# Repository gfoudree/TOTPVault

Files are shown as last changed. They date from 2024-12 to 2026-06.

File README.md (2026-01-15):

# TOTPVault

TOTPVault is a secure hardware vault for storing TOTP codes for two-factor authentication. It is compatible with websites and applications which support authenticators such as Google Authenticator or Authy.

TOTPVault uses an RISC-V ESP32-C3 microcontroller to perform cryptographic operations and storage/generation of TOTP codes with a separate chip to run an isolated USB stack.

<p align="center">
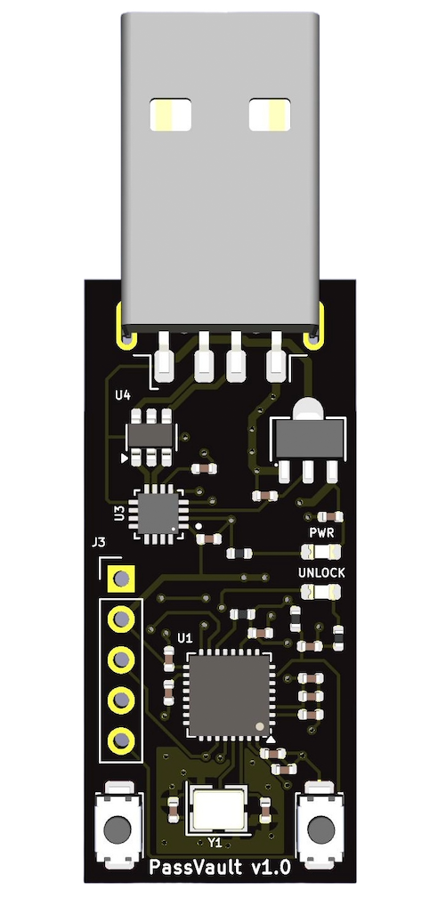
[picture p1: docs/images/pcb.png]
    
</p>

## Demo

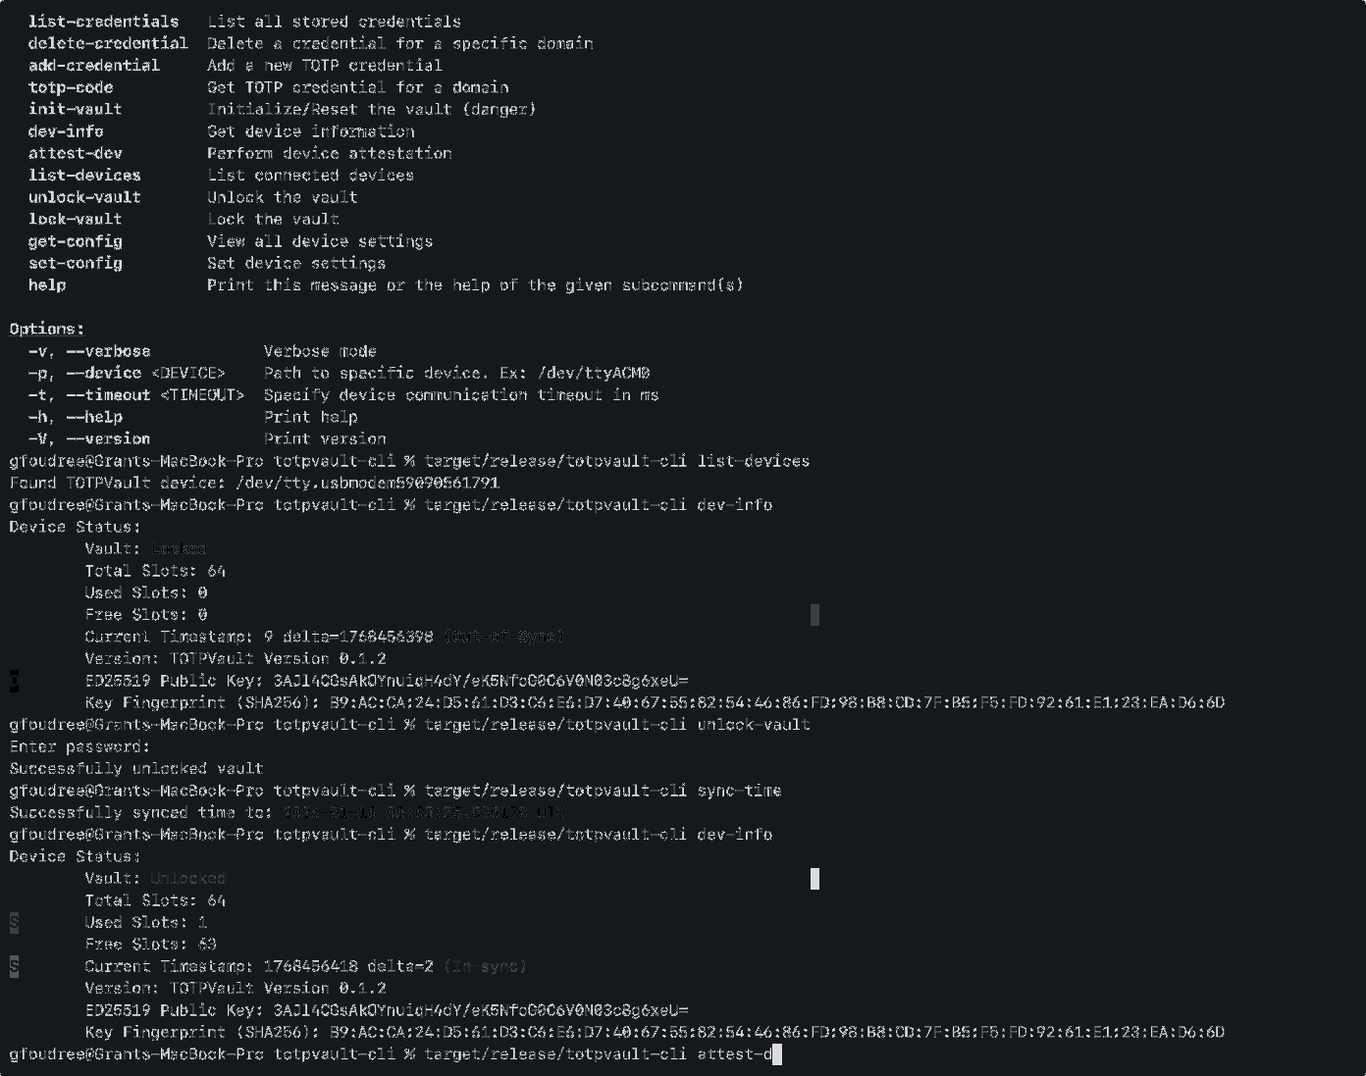
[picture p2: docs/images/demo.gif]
demo


## Features

- Support for up to 64 credentials
- Cross platform, no drivers needed for Linux/MacOS
- Open source firmware, software, and hardware!

### Security Features (summary)
- TOTP secrets stored with AES256, decryption key derived from vault password via PBKDF2
- Trusted firmware via secure boot with attestation available
- ESP32-C3 HW RNG used for cryptographic operations
- USB stack isolated to separate chip to minimize attack surface
- Hardware locked down (JTAG disabled, eFuses set, etc)

# System Architecture
[System Architecture](https://gfoudree.github.io/TOTPVault/system-design/)

## Installation

First, clone the repository and build the `totpvault-cli` tool and build it:

```bash
git clone https://github.com/gfoudree/totpvault
cd totpvault/totpvault-cli
cargo build -r
```

The CLI program will be located at: `target/release/totpvault-cli`
## Documentation

[Documentation](https://gfoudree.github.io/TOTPVault/)

# FAQ

#### Why choose ESP32-C3 for the microcontroller?
The ESP32 chips have strong hardware security features such as HWRNG, encryption/hashing support, secure boot, and encrypted flash.

Other chips have some or all of these features, however the ESP32-C3 is [PSA-L1 certified](https://products.psacertified.org/products/esp32-c3-series/certificates#security-level-1), has good support for Rust firmware, and is affordable.

#### The ESP32 has Wifi/Bluetooth, does this device use either?
No, there is no antenna on the board and the Wifi/Bluetooth stack is disabled in the firmware.

#### If somebody steals my device, can they generate TOTP codes for my accounts?
No, as long as your password is strong they cannot unlock the vault and generate codes.

## Authors

- [@gfoudree](https://www.github.com/gfoudree)

## License

[GNU GPLv3](https://choosealicense.com/licenses/gpl-3.0/)

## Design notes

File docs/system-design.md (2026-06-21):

# System Design

## Security Features

### Secret Storage
  - TOTP secrets are encrypted at rest using AES-256-GCM, ensuring data confidentiality
  - Encryption keys derived from vault password using Argon2id, device has no knowledge of decryption keys without vault password
  - The keys are never stored on the device (ie. the device cannot decrypt any secrets without the user providing the vault password)
  - Encrypted TOTP secrets are stored in NVS (flash) on the same die as the microcontroller, making it difficult to sniff/extract them
  - Secrets are zeroed from memory immediately after use
    <br/><br/>
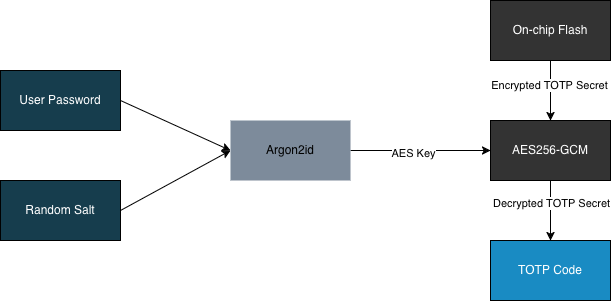
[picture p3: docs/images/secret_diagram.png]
System Diagram
    

### System Firmware
  - ESP32-C3 firmware has secure boot enabled with RSA 3072 signature verification, ensuring only trusted firmware can run
  - Firmware is encrypted using hardware-accelerated AES, providing an additional layer of security and mitigating TOCTOU attacks on secure boot
  - Firmware is written in Rust with minimal `unsafe` regions
  - Device can be attested with a challenge to prove itself
  - ESP32-C3 hardware random number generator is used for cryptographic operations
    <br/><br/>
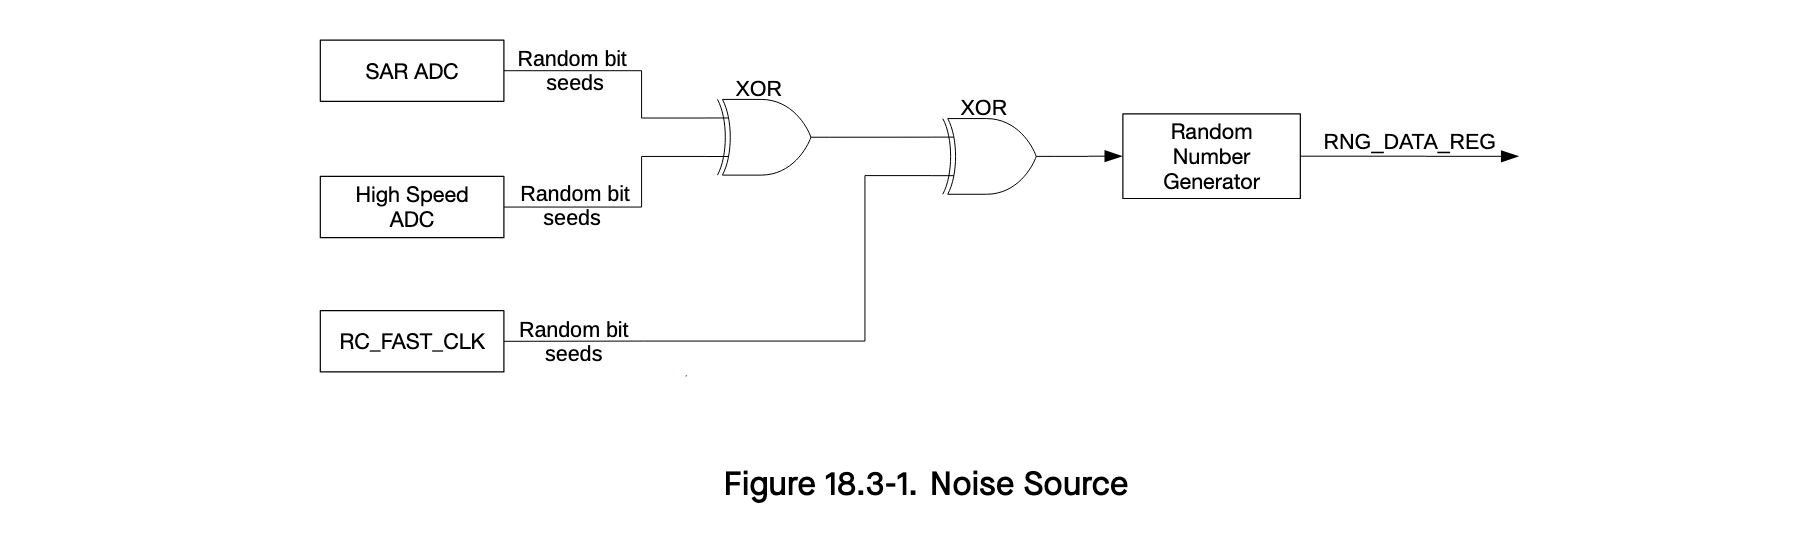
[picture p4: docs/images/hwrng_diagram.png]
HW RNG Design
    

### Hardware Design
  - TOTP secrets are encrypted and stored in on-chip flash memory, substantially complicating attacks to dump or snoop secrets
  - USB interface is delegated to a separate chip (CH343P) from the main microcontroller (ESP32-C3) in order to isolate any USB-level exploits from the main processor
    <br/><br/>
    USB Isolation

  - JTAG interfaces are disabled and eFuses locked down

## Security Limitations

- Communication between the `ESP32 <-> USB/UART Chip <-> Host` is *unencrypted*. After the vault has been unlocked, it is possible for an attacker to sniff these buses for plain-text TOTP codes and TOTP secrets (but only if the sniffing occurs while adding a new credential). It is impossible to extract a TOTP secret once it is stored.

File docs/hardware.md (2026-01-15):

# Hardware Overview

The TOTPVault device is designed with a focus on security and simplicity. Below is a detailed overview of its components and design.

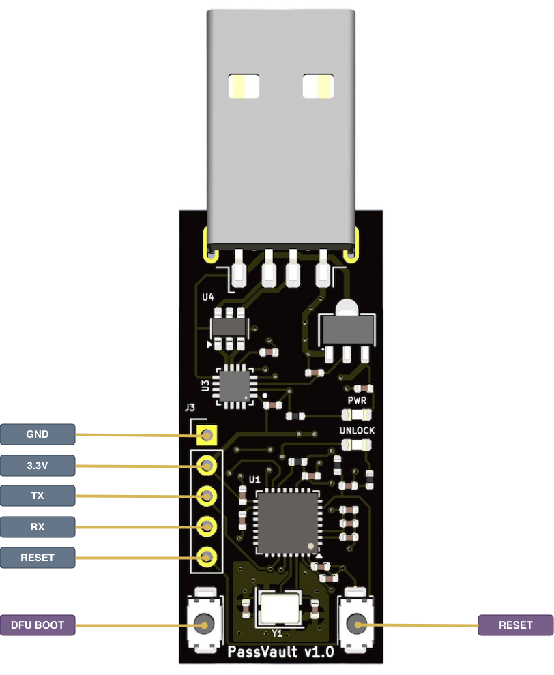
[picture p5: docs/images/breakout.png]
TOTPVault PCB Render


## Specifications

*   **Secure Processor**: ESP32-C3
    *   4MB Flash Storage
*   **USB-to-UART Adapter**: CH343P
*   **USB Connector**: USB-A
*   **Protection**: TVS Diode for static discharge protection on USB lines
*   **Debug Interface**: 5-pin header
    *   TX/RX (serial communication)
    *   3.3V Power
    *   Ground
    *   DFU mode pin
*   **Physical Buttons**:
    *   Reset button
    *   DFU mode button

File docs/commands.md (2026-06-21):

# TOTPVault CLI Commands

## Sync Time
Synchronize the system time with the device.

**Usage:**
```bash
totpvault-cli sync-time
```

**Example:**
```bash
totpvault-cli sync-time
Successfully synced time to: 1704892800
```

## List Credentials
List all stored credentials on the device.

**Usage:**
```bash
totpvault-cli list-credentials
```

**Example:**
```bash
totpvault-cli list-credentials
[Slot 0]: example.com
[Slot 1]: another-site.org
```

## Delete Credential
Delete a credential for a specific domain.

**Usage:**
```bash
totpvault-cli delete-credential --domain <domain_name>
```

**Example:**
```bash
totpvault-cli delete-credential --domain example.com
Successfully deleted credential
```

## Add Credential
Add a new TOTP credential.

**Usage:**
```bash
totpvault-cli add-credential --domain <domain_name>
```

**Example:**
```bash
totpvault-cli add-credential --domain new-service.net
Enter TOTP Secret Key: JBSWY3DPEHPK3PXP
Successfully added credential
```

## Totp Code
Get TOTP credential for a domain.

**Usage:**
```bash
totpvault-cli totp-code --domain <domain_name>
```

**Example:**
```bash
totpvault-cli totp-code --domain example.com
123456
25s remaining
```

## Init Vault
Initialize/Reset the vault (danger).

**Usage:**
```bash
totpvault-cli init-vault
```

**Example:**
```bash
totpvault-cli init-vault
**************** WARNING ****************
Initializing the vault will WIPE EXISTING CREDENTIALS!
Please make sure you will not be locked out of your accounts!

Do you want to continue? (yes/no): yes
Enter vault password:
Enter vault password (confirm):
Successfully initialized vault!
```

## Device Info
Get device information.

Free/Used slots is always `0` when the vault is locked for security reasons

**Usage:**
```bash
totpvault-cli dev-info
```

**Example:**
```bash
totpvault-cli dev-info
Device Status:
	Vault: Unlocked
	Total Slots: 10
	Used Slots: 2
	Free Slots: 8
	Current Timestamp: 1704892800 delta=0 (In-sync)
	Version: 1.0.0
	ED25519 Public Key: IiG0924qxqsDTs7TF8ZAexXJh2ZsRA5hcd9juC0tBGM=
	Key Fingerprint (SHA256): D9:42:BB:FB:7C:D8:B8:47:3D:AF:72:34:98:2B:44:61:4E:BD:8A:AD:32:97:52:C0:14:9C:96:63:5C:22:39:42
```

## Attest Device
Perform device attestation.

`<public_key>` should be the public key (not fingerprint) of the trusted device to send a challenge to.

**Usage:**
```bash
totpvault-cli attest-dev --key <public_key>
```

**Example:**
```bash
totpvault-cli attest-dev -k IiG0924qxqsDTs7TF8ZAexXJh2ZsRA5hcd9juC0tBGM=`
Public key: IiG0924qxqsDTs7TF8ZAexXJh2ZsRA5hcd9juC0tBGM=
Fingerprint (SHA256): D9:42:BB:FB:7C:D8:B8:47:3D:AF:72:34:98:2B:44:61:4E:BD:8A:AD:32:97:52:C0:14:9C:96:63:5C:22:39:42
Successfully attested device
```

## List Devices
List connected devices.

Use `-v` to view detailed information

**Usage:**
```bash
totpvault-cli list-devices
```

**Example:**
```bash
totpvault-cli list-devices
Found TOTPVault device: /dev/ttyACM0
```

## Unlock Vault
Unlock the vault

**Usage:**
```bash
totpvault-cli unlock-vault
```

**Example:**
```bash
totpvault-cli unlock-vault
Enter password:
Successfully unlocked vault
```

## Lock Vault
Lock the vault

**Usage:**
```bash
totpvault-cli lock-vault
```

**Example:**
```bash
totpvault-cli lock-vault
Locked vault
```

## Get Settings
Gets all settings and their values for the device

**Usage:**
```bash
totpvault-cli get-config
```

**Example:**
```bash
totpvault-cli get-config
Device Settings:
        auto-lock: off
```

## Set Autolock
Sets the autolock feature for the vault (locks vault after 10 min)

**Usage:**
```bash
totpvault-cli set-config --vault-autolock <on/off>
```

**Example:**
```bash
totpvault-cli set-config --vault-autolock off
Successfully set setting 'autolock' to 'off'

totpvault-cli set-config --vault-autolock on
Successfully set setting 'autolock' to 'on'
```

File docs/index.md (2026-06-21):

# Introduction

# TOTPVault

TOTPVault is a secure hardware vault for storing TOTP codes for two-factor authentication. It is compatible with websites and applications which support authenticators such as Google Authenticator or Authy.

For a detailed look at the hardware components, see the [Hardware Overview](hardware.md).

Device
# Websites Tested
TOTPVault should work on almost all TOTP-based authentication sites, the list below shows which ones have been validated to be working

| Website | Supported |
|---|---|
| Google | Y |
| Digital Ocean | Y |
| Amazon | Y |
| Microsoft | Y |
| Instagram | Y |
| Paypal | Y |
| eBay | Y |
| Cloudflare | Y |
| Dropbox | Y |
| Github | Y |
| Gitlab | Y |
| Linkedin | Y |
| Protonmail | Y |

# FAQ
### Why choose ESP32-C3 for the microcontroller?
The ESP32 chips have strong hardware security features such as HWRNG, encryption/hashing support, secure boot, and encrypted flash.

Other chips have some or all of these features, however the ESP32-C3 is [PSA-L1 certified](https://products.psacertified.org/products/esp32-c3-series/certificates#security-level-1), has good support for Rust firmware, and is affordable.

### The ESP32 has Wifi/Bluetooth, does this device use either?
No, there is no antenna on the board and the Wifi/Bluetooth stack is disabled in the firmware.

### If somebody steals my device, can they generate TOTP codes for my accounts?
No, as long as your password is strong they cannot unlock the vault and generate codes.

# Troubleshooting
### Device does not show up
Try reinserting the device and look for a USB device with the VID 0x1A86 and PID 0x55D3. 

You can run `dev-info -v` which will print verbose output as to how the device is selected. It is possible another device exists with the same VID/PID in which case use `-p` to specify the path to the exact device

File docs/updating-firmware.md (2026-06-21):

# Updating Firmware

## Requirements
- Linux or Windows system
  - MacOS is not supported due to a driver issue with the USB <-> UART chip CH343p
  - There is a MacOS driver, but it is untested and the status is unknown: [https://github.com/WCHSoftGroup/ch34xser_macos](https://github.com/WCHSoftGroup/ch34xser_macos_)
- Espressif [`esptool`](https://docs.espressif.com/projects/esptool/en/latest/esp32c3/installation.html)

## Steps
- Install `esptool`: `pip install esptool`

- Download the latest firmware version `flash.bin`

- Push and hold the DFU button on the device (left button) while inserting it into the computer, then release the DFU button

- Identify the device `esptool security-info`

```bash
esptool v5.3.0
Connected to ESP32-C3 on /dev/cu.usbserial-TFGTNDFV:
Chip type:          ESP32-C3 in Secure Download Mode

Security Information:
=====================
Flags: 0x000004f5 (0b10011110101)
Key Purposes: (0, 0, 9, 8, 4, 0, 12)
  BLOCK_KEY0 - USER/EMPTY
  BLOCK_KEY1 - USER/EMPTY
  BLOCK_KEY2 - SECURE_BOOT_DIGEST0
  BLOCK_KEY3 - HMAC_UP
  BLOCK_KEY4 - XTS_AES_128_KEY
  BLOCK_KEY5 - USER/EMPTY
Chip ID: 5
API Version: 3
Secure Boot: Enabled
Secure Boot Key Revocation Status:
        Secure Boot Key1 is Revoked
        Secure Boot Key2 is Revoked

Flash Encryption: Enabled
SPI Boot Crypt Count (SPI_BOOT_CRYPT_CNT): 0x1
Icache in UART download mode: Disabled
JTAG: Permanently Disabled
```

- Flash the new firmware with `esptool --chip esp32c3 -p <SERIAL PORT> --no-stub write-flash --no-compress --force --flash-mode dio --flash-freq 80m --flash-size 4MB 0x0 flash.bin`

```bash
esptool v5.3.0
Connected to ESP32-C3 on /dev/cu.usbserial-TFGTNDFV:
Chip type:          ESP32-C3 in Secure Download Mode

Enabling default SPI flash mode...
Configuring flash size...
Warning: Security features enabled, so not changing any flash settings.
Flash will be erased from 0x00000000 to 0x003fffff...
Wrote 4194304 bytes at 0x00000000 in 421.7 seconds (79.6 kbit/s).
Cannot verify written data if encrypted or in secure download mode.

Hard resetting via RTS pin...
```

- Unplug and reinsert the device

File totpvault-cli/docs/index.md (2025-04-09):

# Introduction

Welcome to the TOTPVault documentation. This guide will help you understand how to use and manage your TOTPVault device.

# Websites Tested
TOTPVault should work on almost all TOTP-based authentication sites. The list below just shows which ones have been validated to be working

| Website | Supported |
|---|---|
| Google | Y |
| Digital Ocean | |
| Amazon | |
| Microsoft | |
| Instagram | |
| Paypal | |
| eBay | |
| Cloudflare | |
| Dropbox | |
| Github | |
| Gitlab | |
| Linkedin | |
| Protonmail | |

# FAQ
### Why choose ESP32 for the microcontroller?
The ESP32 has Wifi/Bluetooth, does this device use either? No, there is no antenna on the board and the Wifi/Bluetooth stack is disabled in the firmware

### If somebody steals my device, can they generate TOTP codes for my accounts? 
No, as long as your password is strong they cannot unlock the vault and generate codes

# Troubleshooting
### Device does not show up
Try reinserting the device and looking for a USB device with the VID 0x1A86 and PID 0x55D3. 

You can run `dev-info -v` which will print verbose output as to how the device is selected. It is possible another device exists with the same VID/PID in which case use `-p` to specify the path to the exact device

### "unexpected end of file" Error

```
Unable to get device status from: /dev/tty.usbmodem59090561791
	Error = IO error while reading data: unexpected end of file
```
 The device is taking a while to perform operations, increase the timeout in the user application to wait for it

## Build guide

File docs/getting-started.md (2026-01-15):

# Getting Started

## Installation

First, clone the repository and build the `totpvault-cli` tool:

```bash
git clone https://github.com/gfoudree/totpvault
cd totpvault/totpvault-cli
cargo build -r
```
The executable will be located at `target/release/totpvault-cli`. You can optionally move it to a directory in your `PATH` for easier access.

## Find the TOTPVault device
Insert the device into your computer and search for it
```bash
$ totpvault-cli dev-info

Device Status:
	Vault: Locked
	Total Slots: 64
	Used Slots: 0
	Free Slots: 0
	Current Timestamp: 89 (Out-of-Sync)
	Version: TOTPVault Version 0.1
	Public Key: 2ppFZmElF9eAIi2QaJtwG9y2g3oJAPU/izSje4AbTFQ=
	Key Fingerprint: 4C:FD:D5:D2:9B:70:59:8A:...
```

If you don't see the device, try running with `-v` to see the verbose output. You can manually specify a device with `-p`

## Initialize the vault
Initialize the vault with a strong password. This wipes all existing credentials in the vault, beware!
```bash
$ totpvault-cli init-vault

**************** WARNING ****************
Initializing the vault will WIPE EXISTING CREDENTIALS!
Please make sure you will not be locked out of your accounts!

Do you want to continue? (yes/no):
yes
Enter vault password:
Enter vault password (confirm):
Successfully initialized vault!
```

## Unlock the vault
```bash
$ totpvault-cli unlock-vault

Enter password:
Successfully unlocked vault
```

## Sync time
Time must be synced to the vault on power reset as there is no battery-powered clock. **Inaccurate time will result in invalid TOTP codes**

```bash
$ totpvault-cli sync-time

Successfully synced time to: 2026-01-10 05:44:50.866425 UTC
```

## Verify time-sync and unlocked status
```bash
$ totpvault-cli dev-info

Device Status:
	Vault: Unlocked
	Total Slots: 64
	Used Slots: 0
	Free Slots: 64
	Current Timestamp: 1768023870 delta=2 (In-sync)
	Version: TOTPVault Version 0.1
	ED25519 Public Key: IiG0924qxqsDTs7TF8ZAexXJh2ZsRA5hcd9juC0tBGM=
	Key Fingerprint (SHA256): D9:42:BB:FB:7C:D8:B8:47:3D:AF:72:34:98:2B:44:61:4E:BD:8A:AD:32:97:52:C0:14:9C:96:63:5C:22:39:42
```
`Vault: Unlocked` and `Current Timestamp: 1768023870 (In-sync)` shows that the vault's time is in sync

Note the key fingerprint `D9:42:BB:FB:7C:D8...`. This is the fingerprint of the public key of the device which can be used to authenticate it.

## Add a credential
Login to the account you wish to add and enable a new TOTP credential

When the QR code displays, there should be a option such as "can't scan code" which displays a string such as `r7uk mfjw zboh 3x3u ccij bptu leeq thk6`

Next, run the following command pasting the string from above
```bash
$ totpvault-cli add-credential --domain-name google.com

Enter TOTP Secret Key:
Successfully added credential
```

It is wise to keep a backup 2FA device/method available in case you lose your TOTPVault token!

## List credentials
```bash
$ totpvault-cli list-credentials

[Slot 0]: google.com
```

## Get TOTP code
If the code is incorrect, wait until the next code rolls over (or 30+ sec) since there can be a small delay with the device generating the code
```bash
$ totpvault-cli totp-code -d google.com

056086
11s remaining
```

Refer to the [Commands](commands.md) section for detailed usage of each command.

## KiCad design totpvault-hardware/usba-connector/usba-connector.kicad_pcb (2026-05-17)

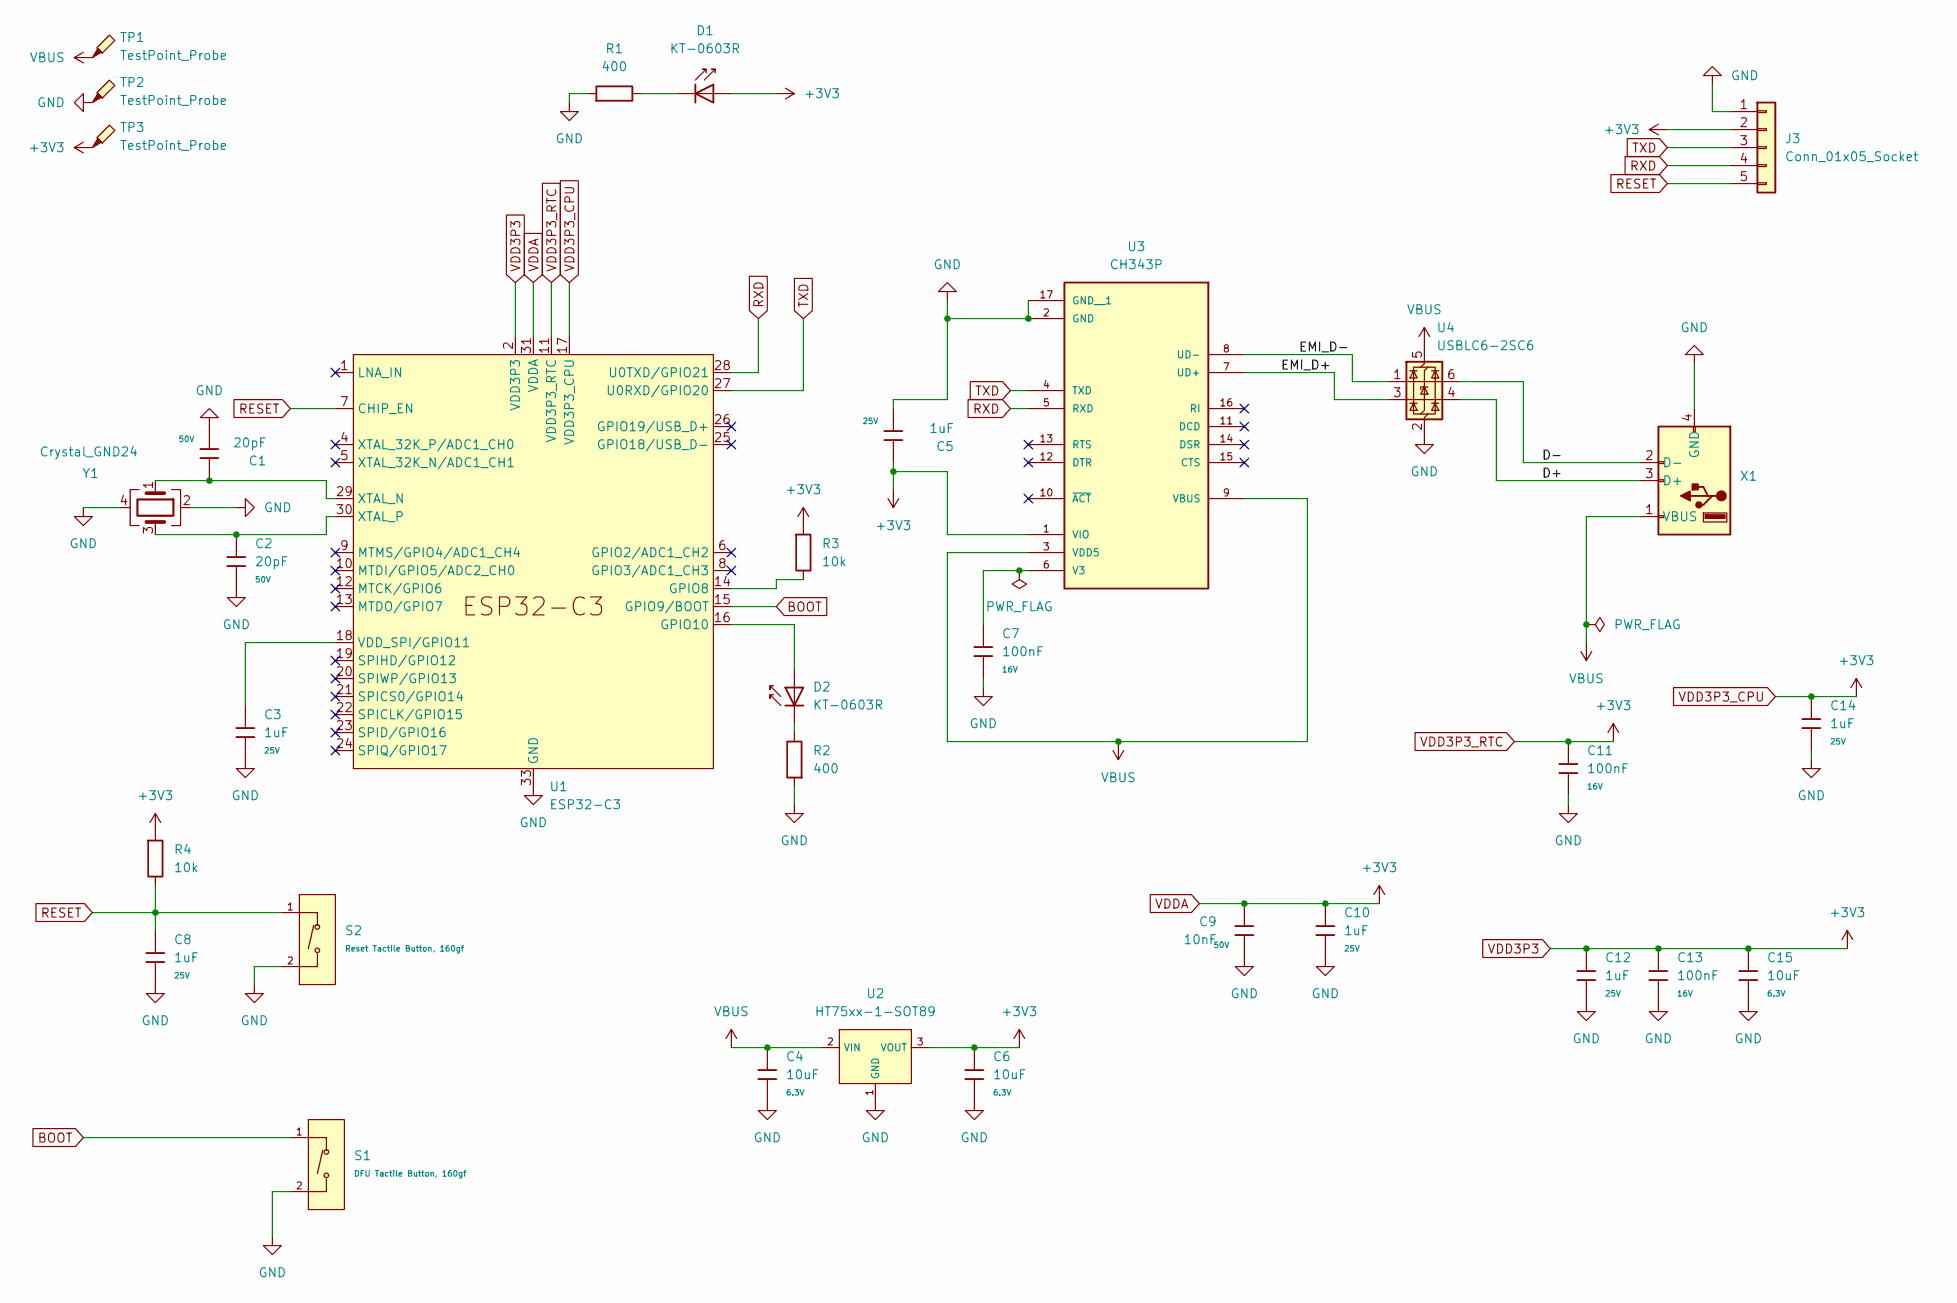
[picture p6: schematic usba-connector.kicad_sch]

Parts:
C1, C2: 20pF; C_0402; Voltage Rated 50V; Tolerance ±5%; Part 0402CG200J500NT; LCSC C1554
C3, C5, C8, C10, C12, C14: 1uF; C_0402; Voltage Rated 25V; Tolerance ±10%; Part CL05A105KA5NQNC; LCSC C52923
C4, C6, C15: 10uF; C_0402; Voltage Rated 6.3V; Tolerance ±20%; Part CL05A106MQ5NUNC; LCSC C15525
C7, C11, C13: 100nF; C_0402; Voltage Rated 16V; Tolerance ±10%; Part CL05B104KO5NNNC; LCSC C1525
C9: 10nF; C_0402; Voltage Rated 50V; Tolerance ±10%; Part CL05B103KB5NNNC; LCSC C15195
D1, D2: KT-0603R; D_0603; Part KT-0603R; LCSC C2286
J3: Conn_01x05_Socket; PinHeader_1x05_P2.54mm_Vertical
R1, R2: 400; R_0402; Overload Voltage (Max) 50V; Tolerance ±1%; Part 0402WGF1200TCE; LCSC C25079
R3, R4: 10k; R_0402; Overload Voltage (Max) 50V; Tolerance ±1%; Part 0402WGF1002TCE; LCSC C25744
S1: DFU Tactile Button, 160gf; SW_TS-1088-AR02016; Voltage Rating (Dc) 12V; Part TS-1088-AR02016; LCSC C720477
S2: Reset Tactile Button, 160gf; SW_TS-1088-AR02016; Voltage Rating (Dc) 12V; Part TS-1088-AR02016; LCSC C720477
TP1, TP2, TP3: TestPoint_Probe; TestPoint_Pad_D1.0mm
U1: ESP32-C3; QFN-32-1EP_5x5mm_P0.5mm_EP3.45x3.45mm
U2: HT75xx-1-SOT89; SOT-89-3_L4.5-W2.5-P1.50-LS4.2-BR; Output Voltage 3.3V; Dropout Voltage 55mV@(1mA); Part HT7533-1; LCSC C14289
U3: CH343P; PARTREV 1E
U4: USBLC6-2SC6; SOT-23-6
X1: USB_A_Molex_48037-2200_Horizontal
Y1: Crystal_GND24; Crystal_SMD_3225-4Pin_3.2x2.5mm

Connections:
/D+: U4.4 (I/O2), X1.3 (D+)
/D-: U4.6 (I/O1), X1.2 (D-)
/EMI_D+: U3.7 (UD+), U4.3 (I/O2)
/EMI_D-: U3.8 (UD-), U4.1 (I/O1)
BOOT: S1.1 (A), U1.15 (GPIO9/BOOT)
GND: C1.2, C2.2, C3.2, C4.2, C5.2, C6.2, C7.2, C8.2, C9.2, C10.2, C11.2, C12.2, C13.2, C14.2, C15.2, J3.1, R1.1, R2.1, S1.2 (B), S2.2 (B), TP2.1, U1.33 (GND), U2.1 (GND), U3.2 (GND), U3.17 (GND__1), U4.2 (GND), X1.4 (GND), Y1.2, Y1.4
unnamed: D1.1, R1.2
unnamed: D2.1, R2.2
unnamed: R3.2, U1.14 (GPIO8)
unnamed: D2.2, U1.16 (GPIO10)
unnamed: C3.1, U1.18 (VDD_SPI/GPIO11)
unnamed: C1.1, U1.29 (XTAL_N), Y1.1
unnamed: C2.1, U1.30 (XTAL_P), Y1.3
unnamed: C7.1, U3.6 (V3)
RESET: C8.1, J3.5, R4.2, S2.1 (A), U1.7 (CHIP_EN)
RXD: J3.4, U1.28 (U0TXD/GPIO21), U3.5 (RXD)
TXD: J3.3, U1.27 (U0RXD/GPIO20), U3.4 (TXD)
VBUS: C4.1, TP1.1, U2.2 (VIN), U3.3 (VDD5), U3.9 (VBUS), U4.5 (VBUS), X1.1 (VBUS)
VDD3P3: C5.1, C6.1, C9.1, C10.1, C11.1, C12.1, C13.1, C14.1, C15.1, D1.2, J3.2, R3.1, R4.1, TP3.1, U1.2 (VDD3P3), U1.3 (VDD3P3), U1.11 (VDD3P3_RTC), U1.17 (VDD3P3_CPU), U1.31 (VDDA), U1.32 (VDDA), U2.3 (VOUT), U3.1 (VIO)

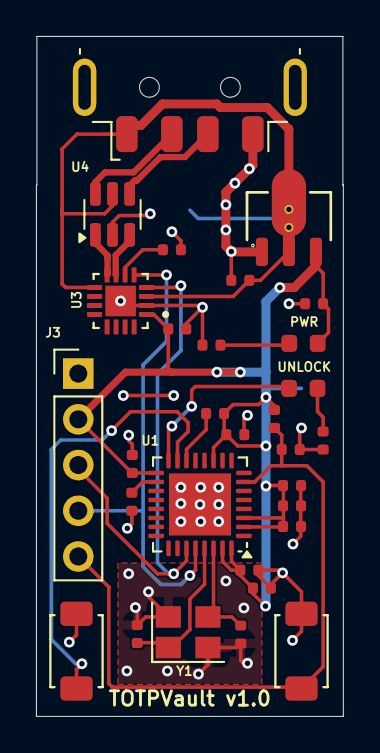
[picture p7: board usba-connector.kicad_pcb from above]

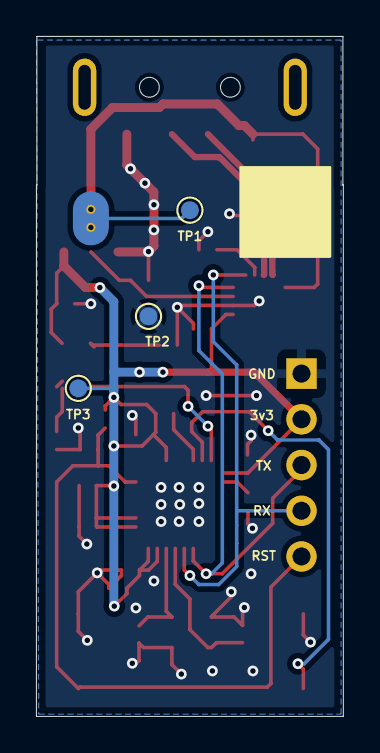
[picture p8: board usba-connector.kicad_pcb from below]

Board: 2 copper layers, 17.1 x 37.8 mm, 33 parts (3 on the bottom side), 19 nets.

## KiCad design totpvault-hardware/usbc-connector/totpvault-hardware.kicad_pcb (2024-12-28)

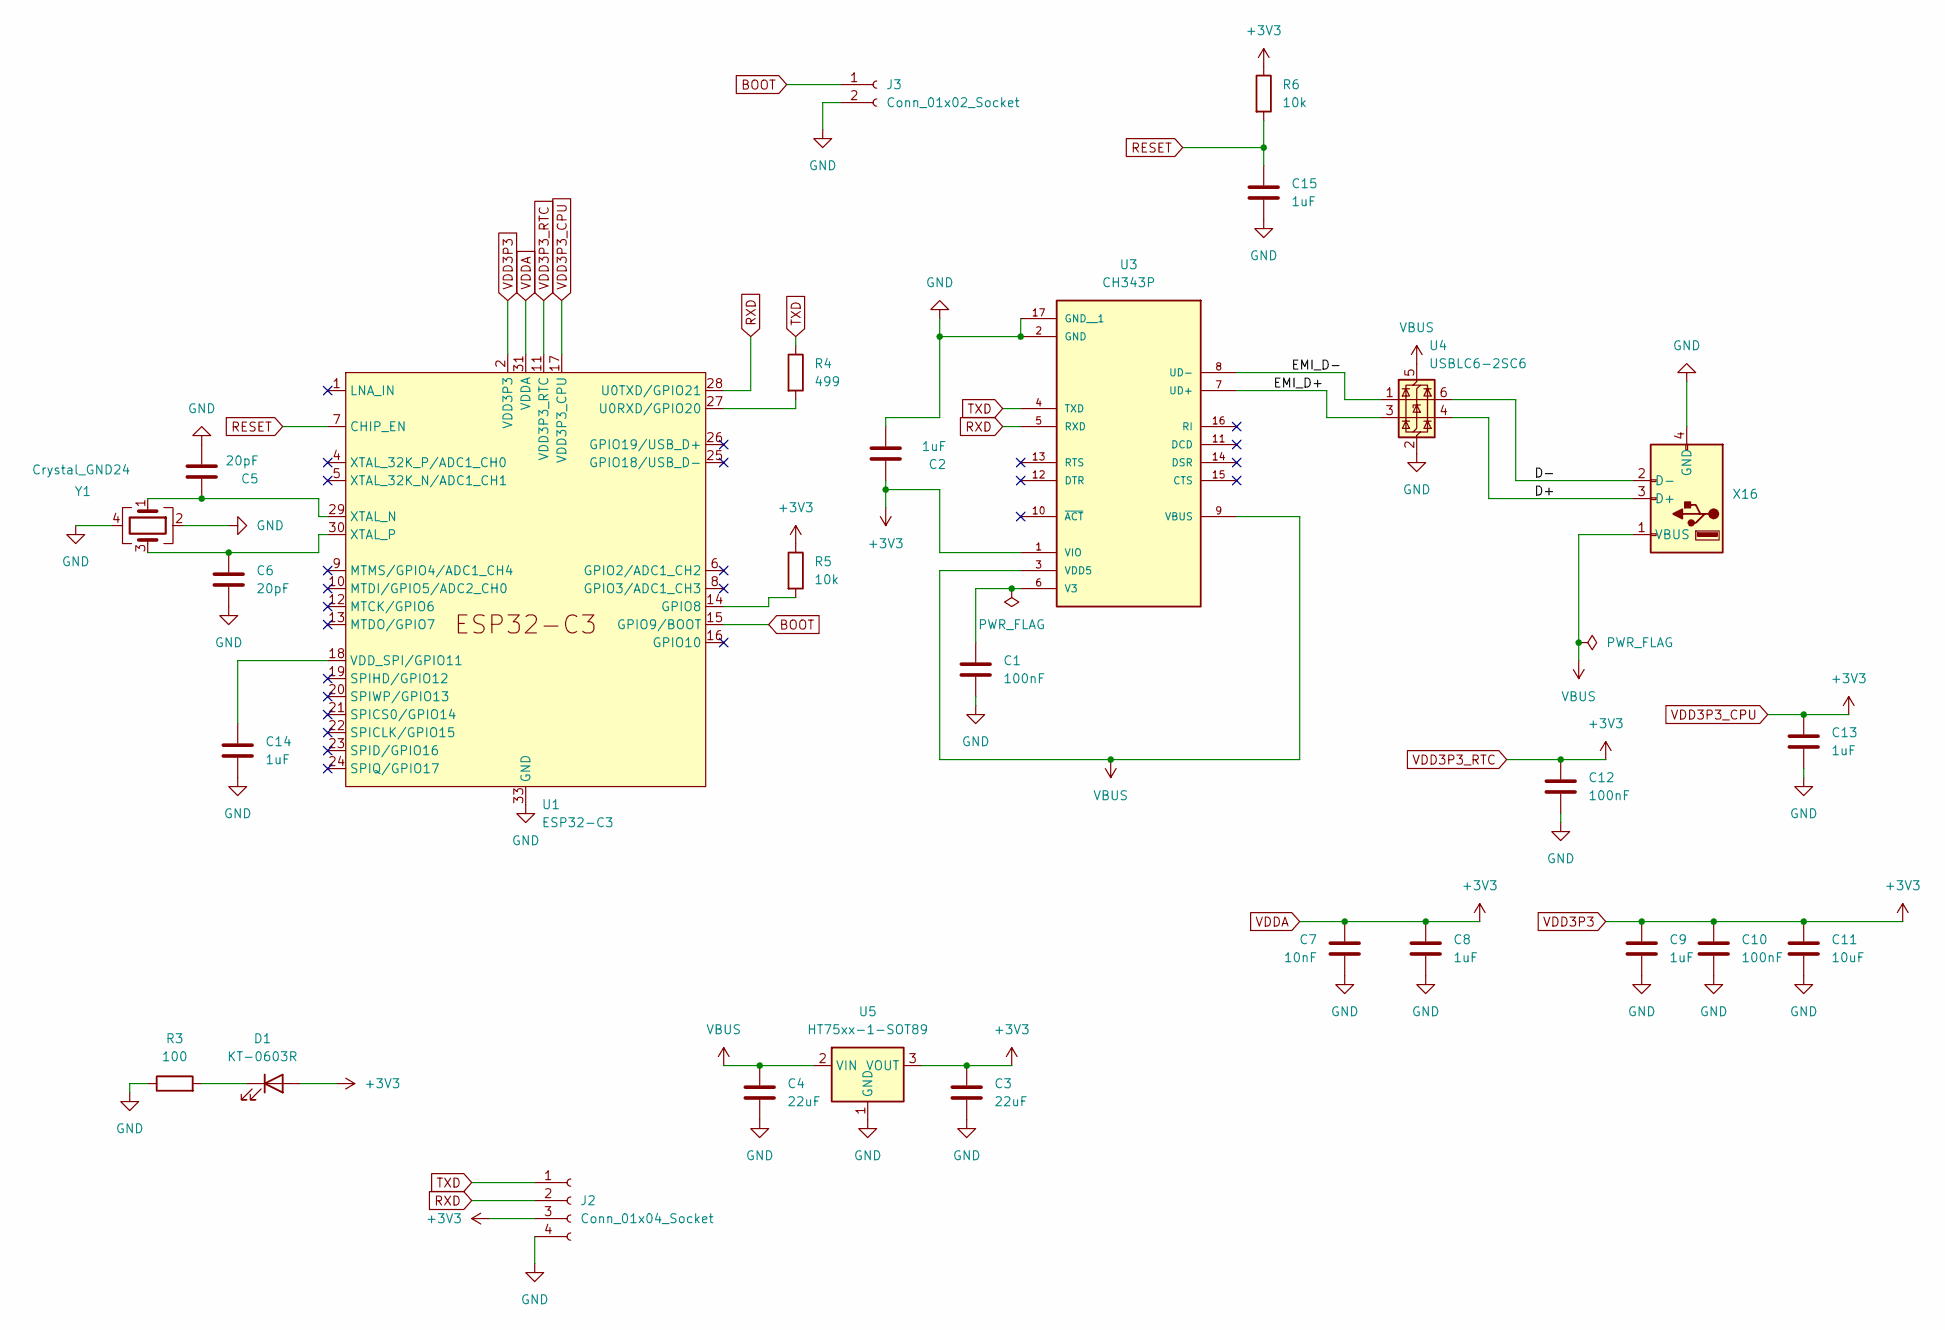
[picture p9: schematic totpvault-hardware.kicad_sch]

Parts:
C1, C10, C12: 100nF; C_0603_1608Metric
C2, C8, C9, C13, C14, C15: 1uF; C_0603_1608Metric
C3, C4: 22uF; C_0603_1608Metric
C5, C6: 20pF; C_0402_1005Metric
C7: 10nF; C_0603_1608Metric
C11: 10uF; C_0603_1608Metric
D1: KT-0603R; LED_0603_1608Metric
J2: Conn_01x04_Socket; PinHeader_1x04_P2.54mm_Vertical
J3: Conn_01x02_Socket; PinHeader_1x02_P2.54mm_Vertical
R3: 100; R_0603_1608Metric
R4: 499; R_0603_1608Metric
R5, R6: 10k; R_0603_1608Metric
U1: ESP32-C3; QFN-32-1EP_5x5mm_P0.5mm_EP3.45x3.45mm
U3: CH343P; PARTREV 1E
U4: USBLC6-2SC6; SOT-23-6
U5: HT75xx-1-SOT89; SOT-89-3
X16: USB_C_Connector
Y1: Crystal_GND24; Crystal_SMD_3225-4Pin_3.2x2.5mm

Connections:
/D+: U4.4 (I/O2), X16.3 (D+)
/D-: U4.6 (I/O1), X16.2 (D-)
/EMI_D+: U3.7 (UD+), U4.3 (I/O2)
/EMI_D-: U3.8 (UD-), U4.1 (I/O1)
BOOT: J3.1, U1.15 (GPIO9/BOOT)
GND: C1.2, C2.2, C3.2, C4.2, C5.2, C6.2, C7.2, C8.2, C9.2, C10.2, C11.2, C12.2, C13.2, C14.2, C15.2, J2.4, J3.2, R3.1, U1.33 (GND), U3.2 (GND), U3.17 (GND__1), U4.2 (GND), U5.1 (GND), X16.4 (GND), Y1.2, Y1.4
unnamed: D1.1 (K), R3.2
unnamed: R5.2, U1.14 (GPIO8)
unnamed: R4.2, U1.27 (U0RXD/GPIO20)
unnamed: C14.1, U1.18 (VDD_SPI/GPIO11)
unnamed: C5.1, U1.29 (XTAL_N), Y1.1
unnamed: C6.1, U1.30 (XTAL_P), Y1.3
unnamed: C1.1, U3.6 (V3)
RESET: C15.1, R6.2, U1.7 (CHIP_EN)
RXD: J2.2, U1.28 (U0TXD/GPIO21), U3.5 (RXD)
TXD: J2.1, R4.1, U3.4 (TXD)
VBUS: C4.1, U3.3 (VDD5), U3.9 (VBUS), U4.5 (VBUS), U5.2 (VIN), X16.1 (VBUS)
VDD3P3: C2.1, C3.1, C7.1, C8.1, C9.1, C10.1, C11.1, C12.1, C13.1, D1.2 (A), J2.3, R5.1, R6.1, U1.2 (VDD3P3), U1.3 (VDD3P3), U1.11 (VDD3P3_RTC), U1.17 (VDD3P3_CPU), U1.31 (VDDA), U1.32 (VDDA), U3.1 (VIO), U5.3 (VOUT)

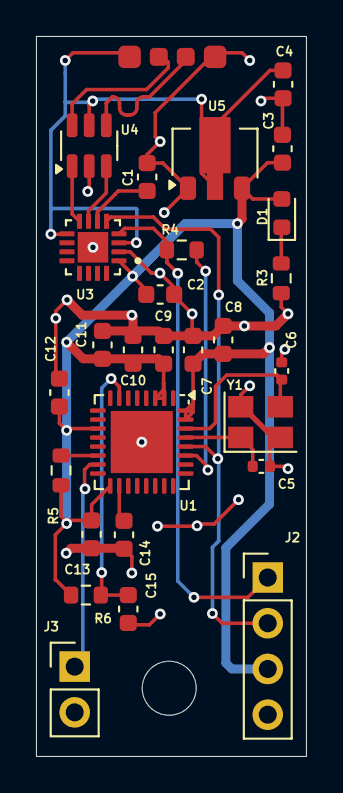
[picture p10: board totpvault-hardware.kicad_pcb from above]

Board: 2 copper layers, 15.0 x 40.0 mm, 28 parts (0 on the bottom side), 18 nets.

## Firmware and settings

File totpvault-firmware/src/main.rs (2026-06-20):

use argon2::{Algorithm, Argon2, Params, Version};
use base64::Engine;
use base64::prelude::BASE64_STANDARD;
use chrono::Utc;
use core::cell::Cell;
use credential::{Credential, MAX_CREDENTIALS};
use critical_section::Mutex;
use crypto::{gen_ed25519_keypair, gen_salt, get_ed25519_public_key_nvs, sign_challenge};
use ed25519_dalek::SECRET_KEY_LENGTH;
use esp_idf_svc::hal::gpio::{Gpio10, InterruptType, Output, PinDriver, Pull};
use esp_idf_svc::hal::timer::{TimerConfig, TimerDriver};
use esp_idf_svc::nvs::{EspDefaultNvsPartition, EspNvsPartition, NvsDefault};
use esp_idf_svc::{
    hal::{gpio::AnyIOPin, prelude::Peripherals, reset::restart, uart, units::Hertz},
    sys,
};
use esp_idf_sys::{ESP_OK, esp_efuse_mac_get_default};
use log::{error, info};
use rmp_serde::Serializer;
use serde::Serialize;
use std::collections::HashMap;
use std::fmt::Debug;
use subtle::ConstantTimeEq;
use totpvault_lib;
use totpvault_lib::*;
use zeroize::{Zeroize, ZeroizeOnDrop};

use crate::crypto::AES_KEY_LEN;

mod credential;
mod crypto;
mod storage;

// Static (global) variable for 'static lifetime. Mutex for safety, Cell<bool> allows multiple mutable references by only allowing 'interior mutability'
static VAULT_STATUS_UNLOCKED: Mutex<Cell<bool>> = Mutex::new(Cell::new(false));

#[derive(Zeroize, ZeroizeOnDrop)] // Have key zeroize on all dropped paths
struct System {
    time_set: bool,
    key: [u8; 32],

    // Authentication rate limiters
    auth_window_ts: i64,
    auth_counter: u32,
    auth_block_until: i64,

    #[zeroize(skip)]
    settings: HashMap<String, String>,
    #[zeroize(skip)]
    nvs_storage: storage::Storage,
    #[zeroize(skip)]
    nvs_partition_handle: EspNvsPartition<NvsDefault>,
}

impl System {
    fn new(nvs_partition: EspNvsPartition<NvsDefault>) -> System {
        System {
            time_set: false,
            key: [0; 32],
            auth_window_ts: 0,
            auth_counter: 0,
            auth_block_until: 0,
            settings: HashMap::new(),
            nvs_storage: storage::Storage::new(nvs_partition.clone()).unwrap(),
            nvs_partition_handle: nvs_partition,
        }
    }

    fn load_settings(&mut self) {
        // Iterate through all of the known settings by their NVS keys
        for key in ALL_SETTINGS {
            match self.nvs_storage.nvs_read_setting(key) {
                Ok(value) => {
                    self.settings.insert(key.to_string(), value);
                }
                Err(_) => {
                    // If setting not found in the NVS, initialize with default and save
                    let default_value = match key {
                        SETTING_AUTOLOCK => AUTOLOCK_OFF,
                        _ => {
                            error!("Unknown setting key during load: {}", key);
                            continue; // Skip unknown settings
                        }
                    };
                    if let Err(write_err) = self.nvs_storage.nvs_write_setting(key, default_value) {
                        error!(
                            "Failed to write default setting {} = {}: {}",
                            key, default_value, write_err
                        );
                    } else {
                        self.settings
                            .insert(key.to_string(), default_value.to_string());
                    }
                }
            }
        }
    }

    /// Updates a K-V setting in the NVS and live system state. Returns the previous value of the setting
    fn set_setting(&mut self, set_msg: &SetSettingMsg) -> Result<String, String> {
        if !set_msg.validate() {
            return Err("Invalid setting key or value".to_string());
        }

        // Get current value of the setting
        let cur_val = self.settings.get(&set_msg.key).unwrap().clone();

        // Update in NVS
        self.nvs_storage
            .nvs_write_setting(&set_msg.key, &set_msg.value)?;

        // Update in current system state
        self.settings
            .insert(set_msg.key.to_string(), set_msg.value.clone());

        Ok(cur_val.to_string())
    }

    fn get_all_settings(&self) -> GetSettingsResponseMsg {
        GetSettingsResponseMsg {
            settings: self.settings.clone(),
        }
    }

    fn setup_ed25519(&mut self) -> Result<(), String> {
        let mut secret_bytes: [u8; SECRET_KEY_LENGTH] = gen_ed25519_keypair().to_bytes();
        self.nvs_storage
            .nvs_write_blob(NVS_KEY_ED25519, &secret_bytes)?;
        secret_bytes.zeroize();
        Ok(())
    }

    fn init_vault(&mut self, cmd_buf: &[u8; 512], read_bytes: usize) -> Result<(), String> {
        let init_msg = rmp_serde::from_slice::<InitVaultMsg>(&cmd_buf[1..read_bytes])
            .map_err(|e| format!("Invalid InitVault message: {}", e))?;

        if !init_msg.validate() {
            return Err("Invalid InitVault message".to_string());
        }

        // Lock the vault and zeroize the key before re-initializing.
        // This handles the case where init_vault is called while the vault is already unlocked.
        critical_section::with(|cs| VAULT_STATUS_UNLOCKED.borrow(cs).set(false));
        self.key.zeroize();

        // Erase NVS partition
        self.nvs_storage
            .format_nvs_partition(self.nvs_partition_handle.clone())?;
        self.setup_ed25519()?;

        // Generate encryption salt and store it in the database
        let salt = gen_salt();
        self.nvs_storage.nvs_write_blob("salt", &salt)?;

        // Derive the encryption key
        let enc_key = Self::derive_encryption_key(init_msg.password.as_str(), &salt)?;

        // Wipe all entries
        for i in 0..MAX_CREDENTIALS {
            Credential::init_credential(i, &mut self.nvs_storage)?;
        }

        // Init metadata
        self.nvs_storage
            .nvs_write_blob_encrypted("magic", &ENCRYPTION_MAGIC, &enc_key)?;

        Ok(())
    }

    fn attest(&mut self, challenge_msg_bytes: &[u8]) -> Result<AttestationResponseMsg, String> {
        let challenge_msg =
            rmp_serde::from_slice::<AuthenticateChallengeMsg>(&challenge_msg_bytes[1..])
                .map_err(|_| "Invalid AuthenticateChallenge message")?;
        if !challenge_msg.validate() {
            return Err("Invalid AuthenticateChallenge message".to_string());
        }

        let challenge_bytes_vec = BASE64_STANDARD
            .decode(challenge_msg.nonce_challenge.clone())
            .map_err(|_| "Invalid AuthenticateChallenge message")?;

        let challenge_bytes: [u8; NONCE_CHALLENGE_LEN] = challenge_bytes_vec
            .try_into()
            .map_err(|_| "Invalid AuthenticateChallenge message")?;

        match sign_challenge(&challenge_bytes, &mut self.nvs_storage) {
            Ok(sig) => {
                let signature_encoded = BASE64_STANDARD.encode(sig.to_vec());
                Ok(AttestationResponseMsg {
                    message: signature_encoded,
                })
            }
            Err(e) => Err(format!("Error signing challenge! {}", e)),
        }
    }

    pub fn derive_encryption_key(
        password: &str,
        salt: &[u8; SALT_LEN],
    ) -> Result<[u8; AES_KEY_LEN], String> {
        let params = Params::new(ARGON2_M_COST, ARGON2_T_COST, ARGON2_P_COST, Some(32))
            .map_err(|e| format!("Invalid Argon2 parameters: {e}"))?;
        let argon2 = Argon2::new(Algorithm::Argon2id, Version::V0x13, params);

        let mut key = [0u8; AES_KEY_LEN];
        argon2
            .hash_password_into(password.as_bytes(), salt, &mut key)
            .map_err(|e| format!("Argon2id key derivation failed: {e}"))?;
        Ok(key)
    }

    fn display_code(&mut self, cmd_buf: &[u8; 512], read_bytes: usize) -> Result<String, String> {
        if self.time_set == false {
            return Err("System time has not been set!".to_string());
        }

        match rmp_serde::from_slice::<DisplayCodeMsg>(&cmd_buf[1..read_bytes]) {
            Ok(display_code_msg) => {
                let index = Credential::credential_name_to_index(
                    display_code_msg.domain_name.to_lowercase(),
                    &self.key,
                    &mut self.nvs_storage,
                )?;
                let mut cred = Credential::get_credential(index, &self.key, &mut self.nvs_storage)?;

                let totp_code = Credential::gen_totp(&cred)?;
                cred.totp_secret_decrypted.zeroize();
                Ok(totp_code)
            }
            Err(_e) => Err("Invalid display code message".to_string()),
        }
    }

    pub fn unlock_vault(
        &mut self,
        cmd_buf: &[u8; 512],
        read_bytes: usize,
        unlocked_led: &mut PinDriver<Gpio10, Output>,
    ) -> Result<(), String> {
        let unlock_msg = rmp_serde::from_slice::<UnlockMsg>(&cmd_buf[1..read_bytes])
            .map_err(|_| "Invalid Unlock message".to_string())?;

        if !unlock_msg.validate() {
            return Err("Invalid Unlock message".to_string());
        }

        // System time can only go forward within a defined delta when vault is unlocked
        let cur_ts = Utc::now().timestamp();

        // Check cooldown timer
        if cur_ts < self.auth_block_until {
            return Err(format!(
                "Too many login attempts, please wait {} seconds",
                LOGIN_COOLDOWN_SECS
            ));
        }

        // Reset rolling authentication window
        if cur_ts - self.auth_window_ts > LOGIN_COOLDOWN_WINDOW_SECS as i64 {
            self.auth_window_ts = cur_ts;
            self.auth_counter = 0;
        }

        // Check the rate limit
        self.auth_counter = self.auth_counter.saturating_add(1);
        if self.auth_counter > MAX_FAILED_AUTH_ATTEMPTS {
            self.auth_block_until = cur_ts + LOGIN_COOLDOWN_SECS as i64;

            return Err(format!(
                "Too many login attempts, please wait {} seconds",
                LOGIN_COOLDOWN_SECS
            ));
        }

        // Read the salt, toss error if it fails ("?"), then try and convert into slice with SALT_LEN and handle error if it fails
        let salt: [u8; SALT_LEN] = match self.nvs_storage.nvs_read_blob("salt")?.try_into() {
            Ok(v) => v,
            Err(_) => {
                return Err(
                    "Database is corrupted, salt is not a valid length. Please reset the database!"
                        .to_string(),
                );
            }
        };

        let key = Self::derive_encryption_key(unlock_msg.password.as_str(), &salt)?;

        // Test if the vault is unlocked
        let decrypted_magic = self
            .nvs_storage
            .nvs_read_blob_encrypted("magic", &key)
            .map_err(|_| {
                "Unable to decrypt value. Corrupted data or wrong password!".to_string()
            })?;

        // Use constant time compare for security, although it's not necessary maybe since GCM mode authenticates decrypted block
        if decrypted_magic.ct_ne(&ENCRYPTION_MAGIC).unwrap_u8() == 1 {
            return Err("Invalid password".to_string());
        }

        self.key = key;
        critical_section::with(|cs| VAULT_STATUS_UNLOCKED.borrow(cs).set(true));

        // Set board LED GPIO10 to on for unlocked
        unlocked_led.set_high().unwrap();

        // Reset auth counter
        self.auth_window_ts = 0;
        self.auth_counter = 0;
        self.auth_block_until = 0;

        Ok(())
    }

    /// Sets the system time counter
    ///
    /// # Overview
    ///
    /// Parses an incoming set time message with a timestamp. Sets system time ONLY if it is greater than the current time AND it's
    /// within an allowed delta `MAX_TIMESTAMP_SET_DELTA` of the current timestamp
    ///
    fn set_time(&mut self, cmd_buf: &[u8; 512], read_bytes: usize) -> Result<(), String> {
        let time_msg = rmp_serde::from_slice::<SetTimeMsg>(&cmd_buf[1..read_bytes])
            .map_err(|_| "Invalid SetTime message".to_string())?;

        if !time_msg.validate() {
            return Err("Invalid SetTime message".to_string());
        }

        let new_unix_timestamp = time_msg.unix_timestamp;

        if self.time_set {
            // Time has been set already, check if the new time is more than the max allowed delta
            let mut current_tv = sys::timeval {
                tv_sec: 0,
                tv_usec: 0,
            };
            let res: i32;
            unsafe {
                res = sys::gettimeofday(&mut current_tv, core::ptr::null_mut());
            }
            if res != 0 {
                return Err("Unable to set time of day!".to_string());
            }

            // Is the new timestamp LESS than the current one OR is the difference between the new and old one > the allowed delta?
            if new_unix_timestamp < current_tv.tv_sec as u64
                || (new_unix_timestamp - current_tv.tv_sec as u64) > MAX_TIMESTAMP_SET_DELTA
            {
                return Err("Invalid timestamp".to_string());
            }
        }
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
fn main() {
    // It is necessary to call this function once, otherwise some patches to the runtime
    // implemented by esp-idf-sys might not link properly. See https://github.com/esp-rs/esp-idf-template/issues/71
    esp_idf_svc::sys::link_patches();
    esp_idf_svc::log::EspLogger::initialize_default();

    #[cfg(debug_assertions)]
    unsafe {
        std::env::set_var("RUST_BACKTRACE", "1");
    }

    // Enable HW RNG. We are not using RF, so we need to use the ADC to feed the RNG. https://docs.espressif.com/projects/esp-idf/en/stable/esp32/api-reference/system/random.html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
    unsafe {
        sys::bootloader_random_enable();
    }
    info!("Hardware RNG enabled");

    let nvs_partition: EspNvsPartition<NvsDefault> = EspDefaultNvsPartition::take().unwrap();
    let mut sys = System::new(nvs_partition.clone());
    sys.load_settings(); // Load settings on system initialization

    let peripherals = Peripherals::take().unwrap();

    let config = uart::config::Config::default()
        .baudrate(Hertz(115_200))
        .flow_control(uart::config::FlowControl::None);

    // Setup status LED and lock button
    let mut unlocked_led = PinDriver::output(peripherals.pins.gpio10).unwrap();
    unlocked_led.set_low().unwrap();
    let mut lock_button = PinDriver::input(peripherals.pins.gpio9).unwrap();
    lock_button.set_pull(Pull::Up).unwrap(); // Pull "BOOT" button up
    lock_button
        .set_interrupt_type(InterruptType::PosEdge)
        .unwrap();

    // Lock button handler
    unsafe {
        lock_button.subscribe(timer_callback_lock_vault).unwrap();
    }

    lock_button.enable_interrupt().unwrap();

    let timer_config = TimerConfig::new().auto_reload(false); // Auto-reload = false for one-shot timer
    let mut autolock_timer = TimerDriver::new(peripherals.timer00, &timer_config).unwrap();
    unsafe {
        autolock_timer.subscribe(timer_callback_lock_vault).unwrap();
    }

    if let Err(e) = sys.first_boot_hook() {
        error!("Critical error on first boot! {e}");
        sys.key.zeroize();
        restart();
    }

    // After this line, logging stops working as UART is taken over for host <-> dev communication
    let mut uart: uart::UartDriver = uart::UartDriver::new(
        peripherals.uart1,
        peripherals.pins.gpio21,
        peripherals.pins.gpio20,
        Option::<AnyIOPin>::None,
        Option::<AnyIOPin>::None,
        &config,
    )
    .expect("Error initializing UART Driver");

    loop {
        std::thread::sleep(std::time::Duration::from_millis(100));

        // Update vault locked LED
        match get_vault_unlock_status() {
            true => unlocked_led.set_high().unwrap(),
            false => {
                unlocked_led.set_low().unwrap();
                sys.key.zeroize(); // Also zeroize out the key. Handles situation when vault is locked via interrupt
            }
        }

        let mut buf: [u8; 512] = [0; 512];
        if let Ok(num_bytes_read) = uart.read(&mut buf, 10) {
            if num_bytes_read > 0 {
                let command = buf[0];

                // Only the CMD_LOCK_VAULT, CMD_DEV_INFO, CMD_LIST, CMD_GET_SETTINGS commands are one byte, the rest should be 2+ bytes
                let min_required_len = match command {
                    CMD_LOCK_VAULT | CMD_DEV_INFO | CMD_LIST | CMD_GET_SETTINGS => 1,
                    _ => 2,
                };
                if num_bytes_read < min_required_len {
                    send_response_message(&mut uart, "Invalid command length", true);
                    continue;
                }

                match command {
                    CMD_SET_TIME => {
                        if get_vault_unlock_status() == false {
                            send_response_message(&mut uart, "Vault Locked!", true)
                        } else {
                            match sys.set_time(&buf, num_bytes_read) {
                                Ok(_) => send_response_message(&mut uart, SUCCESS_MSG, false),
                                Err(e) => send_response_message(&mut uart, e.as_str(), true),
                            }
                        }
                    }
                    CMD_CREATE => {
                        if get_vault_unlock_status() == false {
                            send_response_message(&mut uart, "Vault Locked!", true)
                        } else {
                            match sys.create_entry(&buf, num_bytes_read) {
                                Ok(_) => send_response_message(&mut uart, SUCCESS_MSG, false),
                                Err(e) => send_response_message(&mut uart, e.as_str(), true),
                            }
                        }
                    }
                    CMD_LIST => {
                        if get_vault_unlock_status() == false {
                            send_response_message(&mut uart, "Vault Locked!", true)
                        } else {
                            match Credential::list_credentials(&sys.key, &mut sys.nvs_storage) {
                                Ok(creds) => {
                                    // Transform them into CredentialListMsg
                                    let creds_vec = creds
                                        .iter()
                                        .map(|cred| CredentialInfo {
                                            domain_name: cred.domain_name.clone(),
                                            slot_id: cred.slot_id,
                                        })
                                        .collect();
                                    let cred_list_msg = CredentialListMsg {
                                        credentials: creds_vec,
                                    };
                                    send_message(&mut uart, &cred_list_msg);
                                }
                                Err(e) => send_response_message(&mut uart, e.as_str(), true),
                            }
                        }
                    }
                    CMD_DELETE => {
                        if get_vault_unlock_status() == false {
                            send_response_message(&mut uart, "Vault Locked!", true)
                        } else {
                            if let Ok(del_msg) =
                                rmp_serde::from_slice::<DeleteEntryMsg>(&buf[1..num_bytes_read])
                            {
                                if del_msg.validate() {
                                    match Credential::delete_credential_by_name(
                                        del_msg.domain_name.to_lowercase(),
                                        &sys.key,
                                        &mut sys.nvs_storage,
                                    ) {
                                        Ok(_) => {
                                            send_response_message(&mut uart, SUCCESS_MSG, false)
                                        }
                                        Err(e) => send_response_message(
                                            &mut uart,
                                            format!("Error deleting credential: {}", e).as_str(),
                                            true,
                                        ),
                                    }
                                } else {
                                    send_response_message(
                                        &mut uart,
                                        "Invalid DeleteMsg message",
                                        true,
                                    );
                                }
                            } else {
                                send_response_message(&mut uart, "Invalid DeleteMsg message", true);
                            }
                        }
                    }
                    CMD_DISPLAY_CODE => {
                        if get_vault_unlock_status() == false {
                            send_response_message(&mut uart, "Vault Locked!", true)
                        } else {
                            match sys.display_code(&buf, num_bytes_read) {
                                Ok(totp_code) => {
                                    let totp_code_msg = TOTPCodeMsg {
                                        totp_code: totp_code,
                                        system_timestamp: Utc::now().timestamp() as u64,
                                    };
                                    send_message(&mut uart, &totp_code_msg);
                                }
                                Err(e) => send_response_message(
                                    &mut uart,
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

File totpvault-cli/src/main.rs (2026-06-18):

use crate::dev::TotpvaultDev;
use chrono::Utc;
use clap::{Args, Parser, Subcommand};
use colored::Colorize;
use env_logger::Builder;
use log::{debug, warn};
use totpvault_lib::{MIN_PW_LEN, SystemInfoMsg};
use zeroize::Zeroize;

mod comm;
mod dev;
mod tests;

#[derive(Parser)]
#[command(name = "totpvault-cli")]
#[command(about = "CLI tool to manage TOTPVault", version = "1.0.0")]
struct Cli {
    #[arg(short, long, global = true, required = false, help = "Verbose mode")]
    verbose: bool,
    #[arg(
        short = 'p',
        long,
        global = true,
        required = false,
        help = "Path to specific device. Ex: /dev/ttyACM0"
    )]
    device: Option<String>,
    #[arg(
        short = 't',
        long,
        global = true,
        required = false,
        help = "Specify device communication timeout in ms"
    )]
    timeout: Option<u64>,
    #[command(subcommand)]
    command: Commands,
}

#[derive(Subcommand)]
enum Commands {
    #[command(about = "Synchronize the system time")]
    SyncTime,

    #[command(about = "List all stored credentials")]
    ListCredentials,

    #[command(about = "Delete a credential for a specific domain")]
    DeleteCredential(DomainArgs),

    #[command(about = "Add a new TOTP credential")]
    AddCredential(DomainArgs),

    #[command(about = "Get TOTP credential for a domain")]
    TotpCode(DomainArgs),

    #[command(about = "Initialize/Reset the vault (danger)")]
    InitVault,

    #[command(about = "Get device information")]
    DevInfo,

    #[command(about = "Perform device attestation")]
    AttestDev(PublicKeyArgs),

    #[command(about = "List connected devices")]
    ListDevices,

    #[command(about = "Unlock the vault")]
    UnlockVault,

    #[command(about = "Lock the vault")]
    LockVault,

    #[command(about = "View all device settings")]
    GetConfig,

    #[command(about = "Set device settings")]
    SetConfig(SetConfigArgs),
}

#[derive(Args)]
struct DomainArgs {
    #[arg(
        short = 'd',
        long,
        required = true,
        help = "Domain name of the TOTP code to get"
    )]
    domain_name: String,
}

#[derive(Args)]
struct PublicKeyArgs {
    #[arg(
        short = 'k',
        long,
        required = false,
        help = "Public key of the device to attest"
    )]
    public_key: Option<String>,
}

#[derive(Args)]
struct SetConfigArgs {
    #[arg(long, value_parser = ["on", "off"], help = "Set the vault to automatically lock after 10min ('on' or 'off')")]
    vault_autolock: Option<String>,
}

fn get_device(cli: &Cli) -> Result<String, ()> {
    if let Some(device) = cli.device.clone() {
        Ok(device)
    } else {
        if let Ok(device) = TotpvaultDev::find_device() {
            Ok(device)
        } else {
            Err(())
        }
    }
}

fn dump_device_status(device_status: &SystemInfoMsg) {
    let locked_msg = match device_status.vault_unlocked {
        true => "Unlocked".green(),
        false => "Locked".bold().red(),
    };

    let timestamp_msg = match TotpvaultDev::timesync_check(device_status.current_timestamp) {
        true => {
            let time_delta =
                (Utc::now().timestamp() as u64).abs_diff(device_status.current_timestamp);
            format!(
                "{} delta={} {}",
                device_status.current_timestamp,
                time_delta,
                "(In-sync)".green()
            )
        }
        false => {
            let time_delta =
                (Utc::now().timestamp() as u64).abs_diff(device_status.current_timestamp);
            format!(
                "{} delta={} {}",
                device_status.current_timestamp,
                time_delta,
                "(Out-of-Sync)".red().bold()
            )
        }
    };

    println!(
        "Device Status:\n\tVault: {}\n\tTotal Slots: {}\n\tUsed Slots: {}\n\tFree Slots: {}\n\tCurrent Timestamp: {}\n\tVersion: {}\n\tED25519 Public Key: {}\n\tSerial Number: {}",
        locked_msg,
        device_status.total_slots,
        device_status.used_slots,
        device_status.free_slots,
        timestamp_msg,
        device_status.version_str,
        device_status.public_key,
        device_status.hw_mac
    );

    if let Ok(hash) = TotpvaultDev::public_key_to_hash(&device_status.public_key) {
        println!("\tKey Fingerprint (SHA256): {}", hash);
    } else {
        debug!(
            "Corrupted public key! Key fingerprint: {}",
            device_status.public_key
        );
    }
}
fn main() {
    let cli = Cli::parse();

    if cli.verbose {
        // Set debug! level printing
        Builder::new()
            .filter_level(log::LevelFilter::Debug) // Set the log level to Info
            .init();
    } else {
        env_logger::init();
    }

    if get_device(&cli).is_err() {
        eprintln!("No TOTPVault device found!");
        return;
    }

    let d = get_device(&cli).unwrap();
    let device = d.as_str();

    match cli.command {
        Commands::SyncTime => match TotpvaultDev::sync_time(device, cli.timeout) {
            Ok(utc_time) => println!("Successfully synced time to: {}", utc_time.yellow()),
            Err(error) => eprintln!("Error syncing device time\n\tError = {}", error),
        },
        Commands::ListCredentials => {
            match TotpvaultDev::list_stored_credentials(device, cli.timeout) {
                Ok(credentials) => {
                    for (i, cred) in credentials.iter().enumerate() {
                        println!("[Slot {}]: {}", i, cred.domain_name.green());
                    }
                }
                Err(error) => eprintln!("Error listing stored credentials. {}", error),
            }
        }
        Commands::DeleteCredential(args) => {
            match TotpvaultDev::delete_credential(device, cli.timeout, args.domain_name.as_str()) {
                Ok(_) => println!("Successfully deleted credential"),
                Err(error) => eprintln!(
                    "Error deleting credential \"{}\": {}",
                    args.domain_name, error
                ),
            }
        }
        Commands::AddCredential(args) => {
            let mut totp_secret = rpassword::prompt_password("Enter TOTP Secret Key: ").unwrap();

            // Strip out spaces as some websites (Gmail) have spaces in the secret
            totp_secret = totp_secret.replace(" ", "");
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

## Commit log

2024-10-24 Refactoring message structures, bug fixed with serializing attestation where LF and NL characters broke over serial
    [main.rs]
2024-11-20 Fixed issue with toolchain, compiling again
    [main.rs]
2024-11-26 Major restructuring
    [totpvault-hardware.kicad_pcb, totpvault-hardware.kicad_sch]
2024-12-19 PCB reworking, added labels to GUI
    [dev.rs, main.rs]
2024-12-28 PCB order
    [totpvault-hardware.kicad_pcb, totpvault-hardware.kicad_sch]
2024-12-30 Serial port communication with device working with GUI now
2025-01-12 Countdown timer on GUI working
2025-01-20 Porting to MacOS. Bug with public key from device being truncated to 24 bytes instead of 32
    [dev.rs, main.rs]
2025-01-21 Bugfix for serial port comm, needed to flush boot messages from buffer on first boot
    [dev.rs, main.rs]
2025-01-24 Code cleanup, displaying timesync status and fingerprint
2025-01-25 Code cleanup, added some template functions for device
2025-01-26 Refactoring code to use signals. Time sync working with device
2025-01-31 Added initialize vault button
2025-02-02 Added helper function for communicating with the device
2025-02-07 Updated disabled widgets for when device is unplugged
2025-02-11 Added more CLI functions, moved sync-time function behind vault unlock. Firmware build broken on Linux
    [main.rs]
2025-02-16 Added some testcases, fixed some bugs
    [dev.rs, main.rs]
2025-02-19 Forking to create USB-A connector device
    [totpvault-hardware.kicad_pcb, totpvault-hardware.kicad_sch, usba-connector.kicad_pcb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]
2025-02-20 Added more testcases, fixed some bugs. Currently, adding many entries corrupts the database
    [dev.rs, main.rs]
2025-02-20 Finalized USB-A PCB
    [usba-connector.kicad_pcb, usba-connector.kicad_sch]
2025-02-20 Order ready for USB-A
    [usba-connector.kicad_pcb, usba-connector.kicad_sch]
2025-03-05 Modified USB-A connector to use a physical connector instead of PCB slice due to pricing of ordering 2mm gold-plated PCBs
    [usba-connector.kicad_pcb, usba-connector.kicad_sch]
2025-03-06 Added silkscreen for barcode on PCB order
    [usba-connector.kicad_pcb]
2025-03-11 Fixed 2 major bugs, one with the toolchain being too new causing panics, the other with not waiting for esp32 responses over UART
    [dev.rs]
2025-03-12 Added variable delays for device as 1.5s delay skews TOTP codes and not all commands need this much time
2025-03-13 Added attestation unit tests and fixed max value in firmware
    [main.rs]
2025-03-25 Finalized PCB, added label and fixed solder mask
    [bom.csv, designators.csv, positions.csv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]
2025-03-26 Added logging to firmware boot, configured larger NVS partition but espflash does not work properly
    [partition_table.csv]
2025-03-26 Bugfix, esp32-c3 uses different GPIO pins for TX/RX UART
    [main.rs]
2025-04-04 Fixed bug where device was wiping NVS on each boot
    [main.rs]
2025-12-24 Finalized new board design with JLCPCB basic parts, code cleanup
    [usba-connector.kicad_pcb, usba-connector.kicad_sch]
2026-01-10 Updated documentation with schematics and images, delete GUI project, PCB 3D design cleanup
    [usba-connector.kicad_pcb, usba-connector.kicad_sch]
2026-01-15 Added demo gif and additional documentation
    [partition_table.csv]
2026-02-19 Refactored storage API to be more correct
    [main.rs]
2026-02-24 Fixed bug on first device init where NVS handle became invalid after formatting NVS
    [dev.rs, main.rs]
2026-03-04 Code cleanup, added some additional security to zeroize keys after vault lock via button
2026-05-17 Migrated to Argon2id for KDF, fixed potential panics, added additional zeroize of regions, code formatting cleanup
    [usba-connector.kicad_pcb]
2026-06-18 Fixed issue with Argon2 hashing using too much memory
    [main.rs]
2026-06-18 Code formatting, increased timeout for UART for QEMU
2026-06-19 Moved UART protocol to use length field instead of waits
